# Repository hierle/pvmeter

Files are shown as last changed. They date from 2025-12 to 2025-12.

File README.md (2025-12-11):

# Energy meter - specifically for Solar Panels - for solarbildung.org
Current is sensed via transformer TA12-100 (100:1) and fed to ADC on an ESP32 board.
Sensor values are stored locally on LittleFS, and sent to cloud via Wifi and UMTS modem stick.

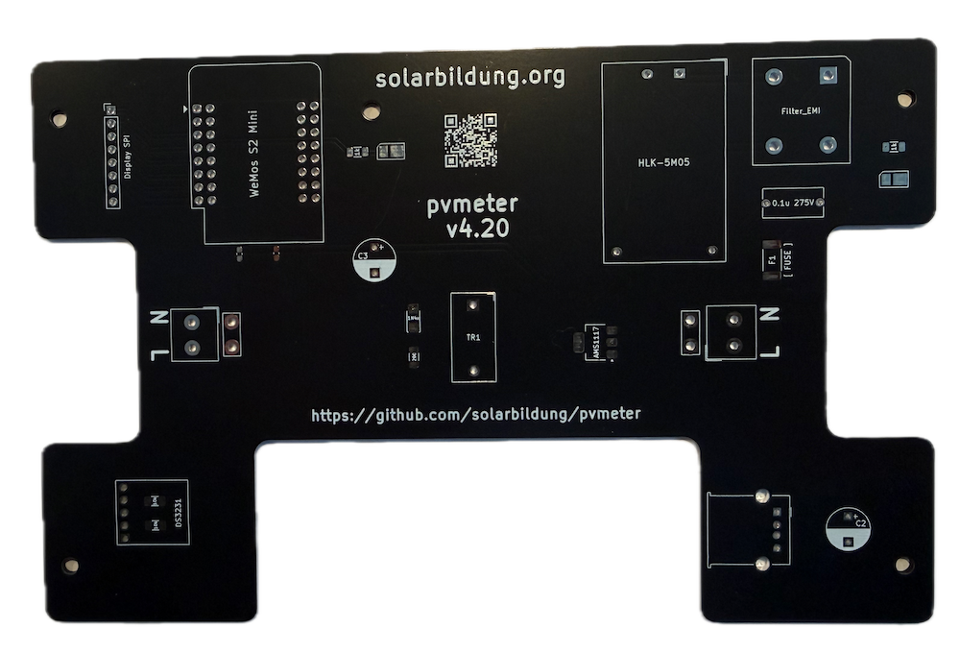
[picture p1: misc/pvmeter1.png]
PVmeter
<br>
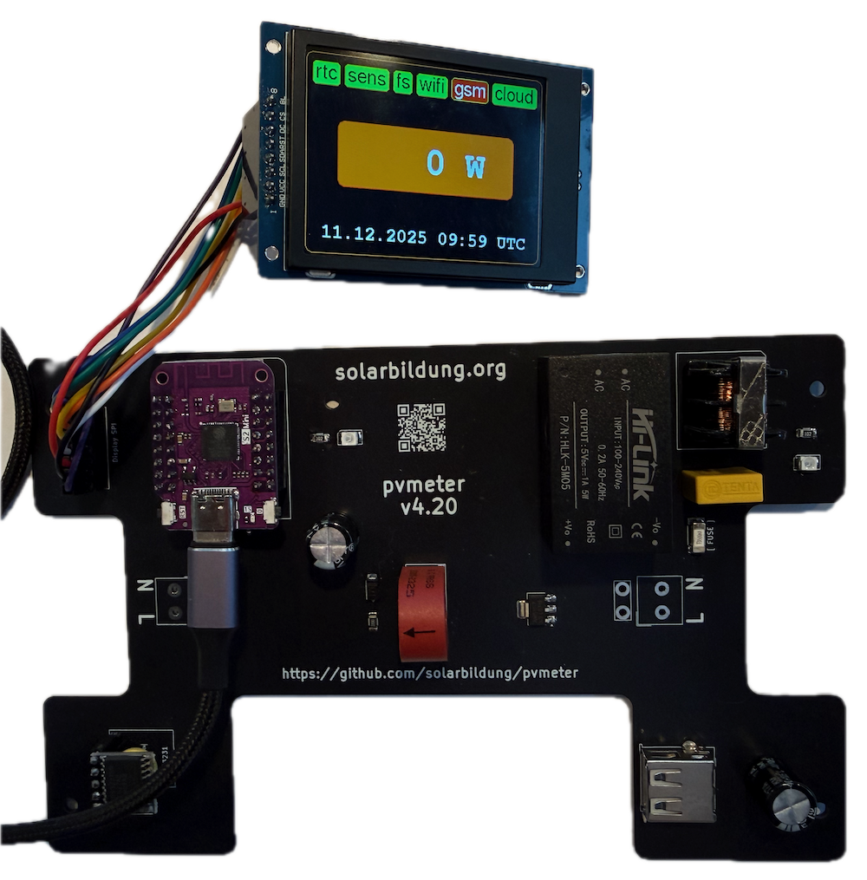
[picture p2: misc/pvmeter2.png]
PVmeter
<br>

Contents:
- ./PCB/ :                  kicad PCB files
- ./cloud/ :                sample CGI script for data collection
- ./misc/ :                 images ...
- ./pvmeter/ :              pvmeter sketch (Arduino IDE)

Compiled and flashed with ArduinoIDE with ESP32 extensions

Features:
- using Lolin S2 mini based on ESP32S2
- transformer TA12-100 rated for 5A max, up to ~1kW
- real time clock DS3231 (I2C) ensures accurate timestamps for data logging
- TFT display via SPI can display status, current energy flow, ...
- USB UMTS modem stick provides reliable data upload even w/o Wifi avail
- USB command line interface for debugging and development

BOM (aliexpress):

| Count | Part number | Description | Usage |
|---|---|---|---|
| 1 | Lolin-S2-miniNI | CPU | CPU |
| | | | |

S2 mini documentation:

https://www.wemos.cc/en/latest/s2/s2_mini.html

How to compile:

in short:<br>
- install ArduinoIDE from arduino.cc
- install the ESP32 Boards from Boards and Library Manager
- select "Lolin S2 mini" board
- on Mac you might need to install pyserial: sudo pip3 install pyserial
- on Linux you might need to install python3-pyserial
- connect the board
- select the corresponding serial port
- open the sketch folder
- adjust config.h and serialnr.h
- compile and flash

For configuration adjust config.h and serialnr.h

config.h:
- WIFI_SSID / WIFI_PASS: credentials for USB UMTS modem
- CLOUD_SERVER: server for data upload
- UPDATE_PERIOD: how often to update TFT display
- SENSOR_PERIOD: how often to measure and upload sensor data
- SENSOR_THRETHOLD: cut off noise below this value
- see also the comments for each entry in config.h

serialnr.h:
- SERIALNUMBER: serial number for specific device (who is sending the data?)

Additional notes:
- you will need a *DATA* USB-C cable, a charging only cable will not work, as it's missing the data pins ;-)

Todos:
- many :)

Have fun!

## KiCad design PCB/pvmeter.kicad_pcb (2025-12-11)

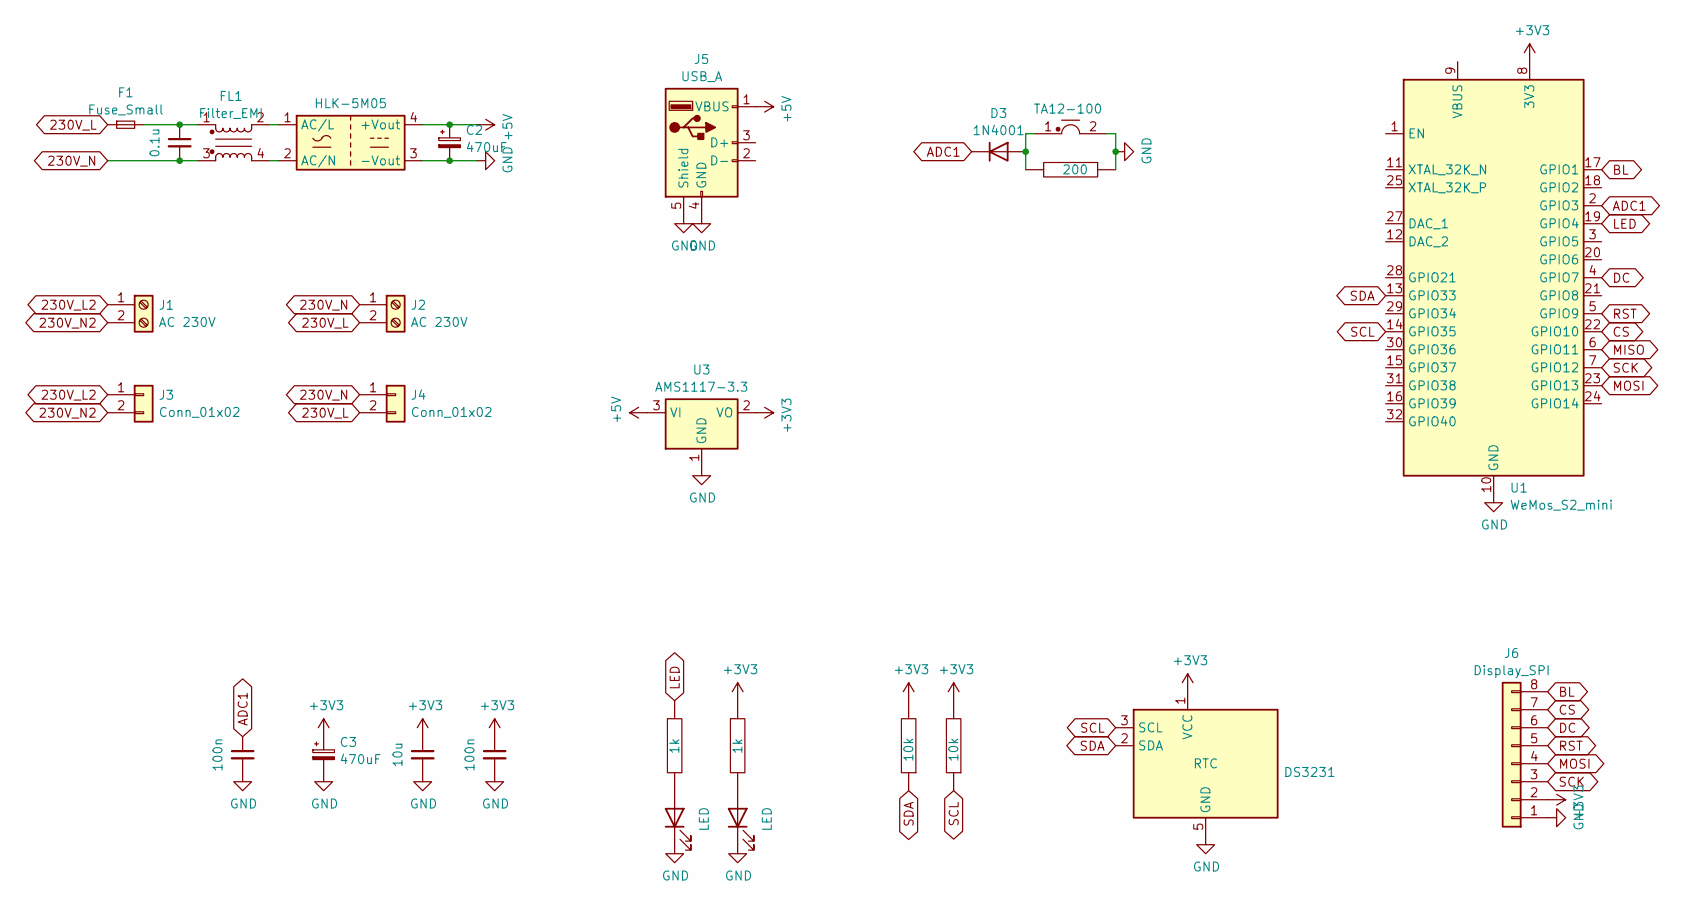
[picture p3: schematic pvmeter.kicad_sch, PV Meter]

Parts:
C1, C4: 100n; C_1206_3216Metric_Pad1.33x1.80mm_HandSolder
C2, C3: 470uF; CP_Radial_D8.0mm_P5.00mm
C5: 10u; C_1206_3216Metric_Pad1.33x1.80mm_HandSolder
C6: 0.1u; C_Rect_L11.0mm_W5.3mm_P10.00mm_MKT
D1, D2: LED; LED_PLCC_2835_Handsoldering
D3: 1N4001; Diode_1N4001_5x2.5mm_HandSolder
F1: Fuse_Small; Fuse_2512_6332Metric_Pad1.52x3.35mm_HandSolder
FL1: Filter_EMI; L_CommonMode_18x20mm_P10x13mm
J1, J2: AC 230V; Terminal_1x02_P7.62mm
J3, J4: Conn_01x02; Solder-Terminal_1x02_P7.62
J5: USB_A; USB_A_Molex_67643_Horizontal
J6: Display_SPI; PinHeader_1x08_P2.54mm_Vertical
PS1: HLK-5M05; HLK-5MXX
R1, R2: 1k; R_1206_3216Metric
R3, R4: 10k; R_1206_3216Metric
R5: 200; R_1206_3216Metric
TR1: TA12-100; Transformer_TA12-100
U1: WeMos_S2_mini; WEMOS-S2-mini
U2: DS3231; RTC_DS3231
U3: AMS1117-3.3; SOT-223

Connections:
230V_L: F1.1, J2.2, J4.2
230V_L2: J1.1, J3.1
230V_N: C6.2, FL1.3, J2.1, J4.1
230V_N2: J1.2, J3.2
+3V3: C3.1, C4.1, C5.1, J6.2, R1.1, R3.2, R4.2, U1.8 (3V3), U2.1 (VCC), U3.2 (VO)
+5V: C2.1, J5.1 (VBUS), PS1.4 (+Vout), U3.3 (VI)
ADC1: C1.1, D3.1 (K), U1.2 (GPIO3)
BL: J6.8, U1.17 (GPIO1)
CS: J6.7, U1.22 (GPIO10)
DC: J6.6, U1.4 (GPIO7)
GND: C1.2, C2.2, C3.2, C4.2, C5.2, D1.1 (K), D2.1 (K), J5.4 (GND), J5.5 (Shield), J6.1, PS1.3 (-Vout), R5.1, TR1.2, U1.10 (GND), U1.26 (GND), U2.5 (GND), U3.1 (GND)
LED: R2.1, U1.19 (GPIO4)
MISO: U1.6 (GPIO11)
MOSI: J6.4, U1.23 (GPIO13)
unnamed: C6.1, F1.2, FL1.1
unnamed: D1.2 (A), R1.2
unnamed: D2.2 (A), R2.2
unnamed: D3.2 (A), R5.2, TR1.1
unnamed: FL1.2, PS1.1 (AC/L)
unnamed: FL1.4, PS1.2 (AC/N)
RST: J6.5, U1.5 (GPIO9)
SCK: J6.3, U1.7 (GPIO12)
SCL: R4.1, U1.14 (GPIO35), U2.3 (SCL)
SDA: R3.1, U1.13 (GPIO33), U2.2 (SDA)

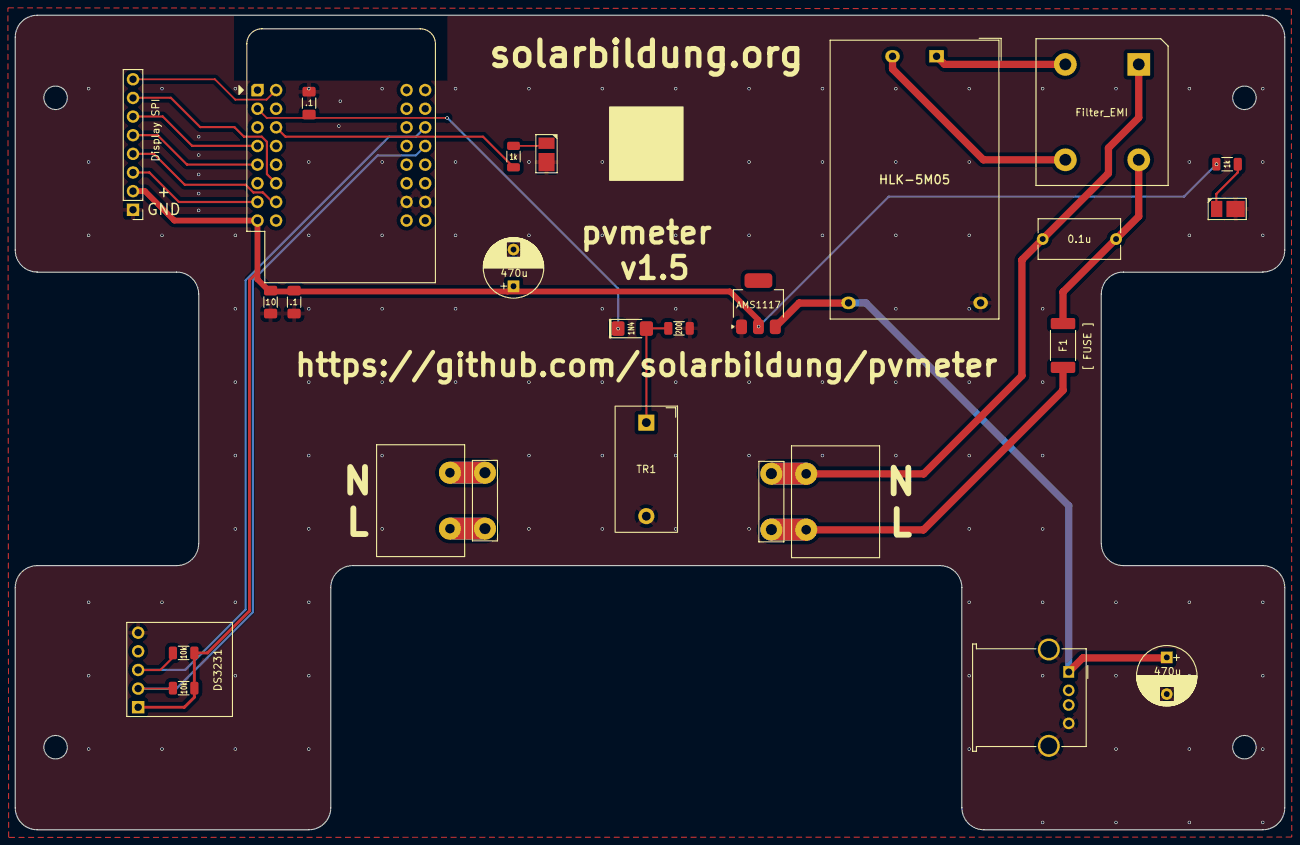
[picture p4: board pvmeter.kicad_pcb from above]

Board: 2 copper layers, 173.0 x 111.0 mm, 27 parts (0 on the bottom side), 23 nets.

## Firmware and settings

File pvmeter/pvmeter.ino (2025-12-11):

//
// Name:    pvmeter.ino
// Version: v1.4.8
//
//

#include <Arduino.h>
#include <Wire.h>
#include <SPI.h>
#include <Adafruit_GFX.h>
#include <Adafruit_ST7789.h>
#include <Fonts/FreeMonoBold12pt7b.h>
#include <Fonts/FreeMonoBold18pt7b.h>
#include <Fonts/FreeMonoBold24pt7b.h>
#include <Fonts/FreeSans9pt7b.h>
#include <Fonts/FreeSans12pt7b.h>
#include <Fonts/FreeSansBold12pt7b.h>
#include <Fonts/FreeSansBold18pt7b.h>
#include <Fonts/FreeSansBold24pt7b.h>
#include <LittleFS.h>
#include <NetworkClientSecure.h>
#include <WiFi.h>
#include <ESPping.h>
//#include <MQTT.h>
#include <WiFiUdp.h>
#include <time.h>

#include "config.h"
#include "pins.h"
#include "serialnr.h"
#include "datetime.h"
#include "flash.h"
#include "display.h"
#include "net.h"
#include "utils.h"

// global variables
status_t status;  // status
time_t now, then, sens, ntpt;
int mode = 0;
tm ntptm;
unsigned long boot_millis;
//SPIClass *vspi = NULL;
//SPIClass *hspi = NULL;

NetworkClientSecure netclient;
//Adafruit_ST7789 display = Adafruit_ST7789(TFT_CS, TFT_DC, TFT_RST);
Adafruit_ST7789 display = Adafruit_ST7789(TFT_CS, TFT_DC, TFT_MOSI, TFT_SCK, TFT_RST);

WiFiUDP udp;

// setup
void setup() {
  //char buffer[32] = {0};
  tm n;
  float sensor;

  // set up serial line
  Serial.begin(115200);
  // init I2C
  Wire.begin();
  delay(500);
  // get time from DS3231 RTC
  if (rtc_get_epoch(&now) == 0) {
    status.rtc = 0;
  } else {
    status.rtc = -1;
  }
  // check for broken RTC ...
  boot_millis = millis();

  Serial.println(F("-----------------------------------"));
  Serial.print(F("Firmware: "));
  Serial.println(FIRMWARE);
  Serial.print(F("Version:  "));
  Serial.println(VERSION);
  Serial.print(F("SerialNr: "));
  Serial.println(SERIALNUMBER);
  Serial.print(F("Date:     "));
  rtc_get_date(&n);
  print_date(n);
  Serial.println(F("-----------------------------------"));

  //vspi = new SPIClass(VSPI);
  //hspi = new SPIClass(HSPI);
  //vspi->begin();

  // set pinmodes
  pinMode(statusled, OUTPUT);
  pinMode(transformer, INPUT);
  pinMode(TFT_BL, OUTPUT);
  digitalWrite(TFT_BL, HIGH);

  // mount filesystem / flash
  if (!LittleFS.begin(true)) {
    Serial.println(F("ERROR: Flash mount failed"));
    status.fs = -1;
  }

  // init display
  init_display(display);

  // test sensor
  if (read_sensor(&sensor, SENSOR_SAMPLE) == 0) {
    status.sensor = 0;
  } else {
    status.sensor = -1;
  }

  // initial display time, sensor and status
  if (rtc_get_date(&n) == 0) {
    status.rtc = 0;
  } else {
    status.rtc = -1;
  }
  display_date(display, n);
  display_status(display, status);
  display_sensor(display, 0);

  // test wifi
  if (wifi_connect() == 0) {
    status.wifi = 0;
  } else {
    status.wifi = -1;
  }
  // test umts
  if (umts_test() == 0) {
    status.umts = 0;
  } else {
    status.umts = -1;
  }
  // test cloud
  if (cloud_test(netclient) == 0) {
    status.cloud = 0;
  } else {
    status.cloud = -1;
  }

  // blink led once on startup
  digitalWrite(statusled, HIGH);
  delay(100);
  digitalWrite(statusled, LOW);

}


void loop() {
  //int bytesrec=0;
  int msglen = 63;
  char usbmsg[msglen] = { 0 };
  float sensor = 0;
  tm n;

  // null buffers
  memset(usbmsg, 0, msglen);

  // get time from RTC
  if (rtc_get_epoch(&now) == 0) {
    status.rtc = 0;
    //Serial.print("RTC epoch: "); Serial.println(now);
  } else {
    status.rtc = -1;
  };
  // TODO: check for dead rtc ... too many things depend on it

  // reconnect wifi
  if (status.wifi == -1) {
    if (wifi_connect() == 0) {
      status.wifi = 0;
      display_status(display, status);
    } else {
      status.wifi = -1;
    }
  }
  // re-test umts
  if (status.umts == -1) {
    if (umts_test() == 0) {
      status.umts = 0;
      display_status(display, status);
    } else {
      status.umts = -1;
    }
  }
  // re-test cloud
  if (status.cloud == -1) {
    if (cloud_test(netclient) == 0) {
      status.cloud = 0;
      display_status(display, status);
    } else {
      status.cloud = -1;
    }
  }

  // read sensor
  if (now >= sens + SENSOR_PERIOD) {
    sens = now;
    // sample for 100ms ~ 5x sinus wave
    if (read_sensor(&sensor, SENSOR_SAMPLE) == 0) {
      status.sensor = 0;
    } else {
      status.sensor = -1;
    }
    // display
    display_sensor(display, sensor);
    // log to fs
    if (log_sensor(LittleFS, sensor) == 0) {
      status.fs = 0;
    } else {
      status.fs = -1;
    }
    // log to cloud
    if (cloud_sensor(netclient, sensor) == 0) {
      status.cloud = 0;
    } else {
      status.cloud = -1;
    }
  }

  // update time and status on display, once per minute
  if (now >= then + UPDATE_PERIOD) {
    then = now;
    if (rtc_get_date(&n) == 0) {
      status.rtc = 0;
    } else {
      status.rtc = -1;
    }
    display_date(display, n);
    // status
    display_status(display, status);
  }

  // get ntp time and update rtc
  if(now >= ntpt + NTP_PERIOD) {
    ntpt = now;
    if(status.wifi==0) {
      Serial.print("getting NTP time... ");
      udp.begin(NTP_LOCAL_PORT);
      send_ntp_packet(NTP_SERVER);
      delay(1000);
      if(receive_ntp_packet(&ntptm)==0) { status.ntp = 0; Serial.println("ok."); }
      else { status.ntp = -1; Serial.println("failed."); }
      udp.stop();
      //showTime();
    }
  }

  // serial (USB) from PC/user
  if (Serial.available()) {
    //bytesrec = Serial.readBytes(usbmsg,msglen);
    Serial.readBytes(usbmsg, msglen);
    handle_usb(usbmsg);
  }
  // being polite :)
  delay(10);
}
// end of main loop




// handle serial from pc
void handle_usb(char *msg) {
  char *ptr;
  tm n;
  time_t ut;

  // help
  if ((msg[0] == 'h') || (msg[0] == '?')) {
    print_help();
    return;
  }
  // status
  if (strncmp(msg, "status", 6) == 0) {
    print_status(status);
    return;
  }
  // date
  if (strncmp(msg, "date", 4) == 0) {
    rtc_get_date(&n);
    print_date(n);
    return;
  }
  // unixtime
  if (strncmp(msg, "unixtime", 8) == 0) {
    rtc_get_epoch(&ut);
    Serial.println(ut);
    return;
  }
  // format
  if (strncmp(msg, "format", 6) == 0) {
    LittleFS.format();
    return;
  }
  // mkdir
  if (strncmp(msg, "mkdir", 5) == 0) {
    // strip off \n, \r and spaces
    ptr = strchr(msg, 0x0a);
    if (ptr != NULL) { *ptr = 0; }
    ptr = strchr(msg, 0x0d);
    if (ptr != NULL) { *ptr = 0; }
    ptr = strchr(&msg[6], 0x20);
    if (ptr != NULL) { *ptr = 0; }
    if (!LittleFS.mkdir(&msg[6])) { Serial.print(F("ERROR: ")); }
    return;
  }
  // rmdir
  if (strncmp(msg, "rmdir", 5) == 0) {
    // strip off \n and \r and spaces
    ptr = strchr(msg, 0x0a);
    if (ptr != NULL) { *ptr = 0; }
    ptr = strchr(msg, 0x0d);
    if (ptr != NULL) { *ptr = 0; }
    ptr = strchr(&msg[6], 0x20);
    if (ptr != NULL) { *ptr = 0; }
    if (LittleFS.rmdir(&msg[6])) { Serial.println(F("removed")); }
    return;
  }
  if (strncmp(msg, "ls", 2) == 0) {  // ls
    // strip off \n and \r
    ptr = strchr(msg, 0x0a);
    if (ptr != NULL) { *ptr = 0; }
    ptr = strchr(msg, 0x0d);
    if (ptr != NULL) { *ptr = 0; }
    if (strlen(&msg[3]) == 0) { msg[3] = 0x2f; }
    //Serial.print("->");Serial.print(&msg[3]);Serial.println("<-");
    list_dir(LittleFS, &msg[3], 3);
    return;
  }
  // cat
  if (strncmp(msg, "cat", 3) == 0) {
    // strip off \n and \r and spaces
    ptr = strchr(msg, 0x0a);
    if (ptr != NULL) { *ptr = 0; }
    ptr = strchr(msg, 0x0d);
    if (ptr != NULL) { *ptr = 0; }
    ptr = strchr(&msg[4], 0x20);
    if (ptr != NULL) { *ptr = 0; }
    read_file(LittleFS, &msg[4]);
    return;
  }
  // rm
  if (strncmp(msg, "rm", 2) == 0) {
    // strip off \n and \r and spaces
    ptr = strchr(msg, 0x0a);
    if (ptr != NULL) { *ptr = 0; }
    ptr = strchr(msg, 0x0d);
    if (ptr != NULL) { *ptr = 0; }
    ptr = strchr(&msg[3], 0x20);
    if (ptr != NULL) { *ptr = 0; }
    delete_file(LittleFS, &msg[3]);
    return;
  }
  // print data from today ( YYYYMMDD,unixtime,sensor )
  if (strncmp(msg, "data", 4) == 0) {
    char datafile[32] = { 0 };
    tm now;
    rtc_get_date(&now);
    sprintf(datafile, "/data/%04d%02d%02d.log", now.tm_year, now.tm_mon, now.tm_mday);
    read_file(LittleFS, datafile);
    return;
  }
  // wifi scan
  if (strncmp(msg, "wifiscan", 8) == 0) {
    wifi_scan();
    return;
  }
  // wifi connect
  if (strncmp(msg, "wificonn", 8) == 0) {
    if (wifi_connect() == 0) {
      status.wifi = 0;
    } else {
      status.wifi = -1;
    };
    return;
  }
  // wifi status
  if (strncmp(msg, "wifistatus", 10) == 0) {
    wifi_status();
    return;
  }
  // cloud test
  if (strncmp(msg, "cloudtest", 9) == 0) {
    if (cloud_test(netclient) == 0) {
      status.cloud = 0;
    } else {
      status.cloud = -1;
    };
    return;
  }

  // if we reached here ... it's an unsupported/unknow command ;)
  Serial.println(F("unknown command, try \"help\""));
}


void print_help() {
  Serial.println();
  Serial.print(FIRMWARE);
  Serial.print(F(" v"));
  Serial.println(VERSION);
  Serial.println();
  Serial.println(F("available commands:"));
  Serial.println();
  Serial.println(F("h (or ?)                 : this help"));
  Serial.println(F("status                   : system status"));
  Serial.println(F("date                     : current date / time"));
  //Serial.println(F("setdate <date>           : set rtc date/time, e.g. setdate {14,55,0,2025,1,2}  for 20250102 14:55:00"));
  Serial.println(F("unixtime                 : unixtime (seconds since 1970/01/01)"));
  Serial.println(F("ls <dir>                 : list directory, e.g. ls /data"));
  Serial.println(F("mkdir <dir>              : create directory, e.g. mkdir /tmp"));
  Serial.println(F("rmdir <dir>              : remove directory, e.g. rmdir /tmp"));
  Serial.println(F("cat <file>               : show content of file, e.g. cat /data/20250131.log"));
  Serial.println(F("rm <file>                : remove file"));
  Serial.println(F("wifiscan                 : wifi scan"));
  Serial.println(F("wificonn                 : wifi connect"));
  Serial.println(F("wifistatus               : wifi status"));
  Serial.println(F("cloudtest                : cloud test"));
  Serial.println(F("data                     : print all data from today"));
  Serial.println();
}

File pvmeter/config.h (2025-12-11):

#pragma once
//
// config.h
//

#define VERSION "1.4.8"
#define FIRMWARE "PVMeter"
#define TZ "UTC"

#define USE_HSPI_PORT

// wifi / network
#define WIFI_SSID "mySSID"
#define WIFI_PASS "myPASS"
//#define WIFI_TIMEOUT 5

// umts wifi stick
//#define WIFI_SSID "mySSID"
//#define WIFI_PASS "myPASS"
#define WIFI_TIMEOUT 5

// ping test (gsm/umts status)
//#define PING_ADDRESS "8, 8, 8, 8"
#define PING_ADDRESS "vodafone.com"

// cloud server
#define CLOUD_SERVER "solarbildung.faun.org"
//#define CLOUD_SERVER "cloud.solarbildung.org"
#define CLOUD_PORT 443
#define CLOUD_GET "/status.txt"
#define CLOUD_POST "/pvmeter"

// update time and status every 10 seconds
#define UPDATE_PERIOD 10

// sensor
//#define SENSOR_PERIOD 60 // seconds between sensor measure
#define SENSOR_PERIOD 5 // seconds between sensor measure
//#define SENSOR_THRETHOLD 35 // cut noise below 35 watt
#define SENSOR_THRETHOLD 5 // cut noise below 5 watt
#define SENSOR_SAMPLE 100 // sample for 100x1ms
//#define SENSOR_FILE "/data/data.log" // fallback in case we do not have RTC

// update ntp time every 5 minutes
//#define NTP_PERIOD 300
#define NTP_PERIOD 30
#define NTP_SERVER "de.pool.ntp.org"
#define MAX_TIME_DIFF 60  // max time diff between RTC and NTP

// I2C
#define I2C_RTC_ADDR     0x68
//#define I2C_DISPLAY_ADDR 0x3C
//#define I2C_EPROM_ADDR     0x22

// mode
#define MODE_AP            1  // access point
#define MODE_WIFI          2  // wifi connect

// status
#define OK          0
#define FAILED      -1

// status
typedef struct {
  int all;
  int rtc = -1;
  int sensor = -1;
  int fs = -1;
  int tft = -1;
  int wifi = -1;
  int umts = -1;
  int cloud = -1;
  int ntp = -1;
} status_t;
